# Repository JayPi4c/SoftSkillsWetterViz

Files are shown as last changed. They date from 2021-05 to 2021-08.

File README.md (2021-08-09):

# Wetter-L

## Inhaltsverzeichnis
* [Kurzbeschreibung](#kurzbeschreibung)
* [Inbetriebnahme](#inbetriebnahme)
  * [Demo](#demo)
* [Hardware](#hardware)
* [Software](#software)
  * [Bibliotheken](#bibliotheken)
  * [Boardmanager](#boardmanager)
  * [Code](#code)
* [Features](#features)
  * [Darstellung des Wetters](#darstellung-des-wetters)
  * [Darstellung einer Animation](#darstellung-einer-animation)

## Kurzbeschreibung

Dieser Code gehört zu dem Wetter-Gadget, welches für das Modul Soft Skills und technische Kompetenzen als Semester-Projekt ensteht. Die Aufgabe war es, Wetterdaten, bereitgestellt von [OpenWeatherMap](https://openweathermap.org/), mittels eines WiFi-Fähigen Arduinos und LEDs darzustellen.

Weitere Bedingungen des Projektes waren es, dass mindestens ein Teil des Gadgets aus dem 3D-Drucker kommen oder mit dem Laser-Cutter ausgeschnitten worden sein sollte. Nach einem differenziertem Brainstorming sind wir zu folgenden Prototypen gekommen:
Prototyp

## Inbetriebnahme
Um das Gadget starten zu können muss der Code heruntergeladen werden. Sind die entsprechenden [Biblitheken](#bibliotheken) und der [Boardmanager](#boardmanager) installiert, muss nur noch die `secrets.h` Datei erstellt und mit Inhalt gefüllt werden. Dies lässt sich durch kopieren des Inhalts aus der `secrets_example.h` erreichen, webei die Variablen noch mit den persönlichen Daten gefüllt werden müssen. `SSID` und `Passwort` beziehen sich auf das lokale WLAN-Netzwerk mit dem sich der Mikro-Controller verbinden soll. Den Schlüssel für `OWM_API_KEY` erhält man kostenlos von [OpenWeatherMap.org](https://openweathermap.org/price) nach einer Anmeldung. Den Token für die `BLYNK_API_KEY`-Variable erhält man aus der Blynk App, nachdem man den QR-Code eingescannt hat.
WhatsApp Image 2021-04-09 at 17 00 35

### Demo
Demo-Video (https://www.youtube.com/watch?v=5HPHukewiGE)

## Hardware
- LOLIN(WEMOS) D1 mini Lite 
- LED-Stripe
- LED

## Software

### Bibliotheken
- FastLED (v3.3.3)
- ArduinoJson (v6.17.2)
- Blynk (v1.0.0-beta.3)
### Boardmanager
Um für den ESP8266 Code kompilieren zu können, muss in den Arduino Einstellungen im Menüpunkt "weitere Board manager URLs" folgender Link hinzugefügt werden: http://arduino.esp8266.com/stable/package_esp8266com_index.json. Anschließend kann der entsprechend Board Manager von Arduino heruntergeladen werden.

### Code
Der Code lässt sich grob in vier Abschnitte unterteilen:
* Bibliotheken und globale Variablen
* Einbindung der Blynk API
* `setup`- und `loop`-Funktionen
* weitere Helper-Funktionen

Um zu verstehen, wie die Anbindung mit Blynk funktioniert ist die [Dokumentation](https://docs.blynk.cc/) der beste Ort für Fragen und um ein Verständis zu entwickeln.
In der `setup`-Funktion wird der LED-Streifen initialisiert und eine Verbindung zu Blynk aufgebaut. Hierbei werden vor dem Verbindungsaufbaue alle Scheiben mit einer zufälligen Farbe initialisiert. Konnte eine Verbindung hergestellt werden, so gehen alle LEDs aus und es werden die Wetterdaten von der API bezogen und dargstellt. Sollte ein Fehler auftreten, so leuchten alle Scheiben rot auf.
In der `loop`-Funktion werden, abhängig von dem aktuellen Modus neue Wetterdaten bezogen oder es wird eine Animation dargestellt. Hierbei wird sich viel der Helper-Funktionen bedient.

Diagramm

Die Helper-Funktionen umfassen Methoden zur Darstellung der Wetterdaten und zum anfordern der Wetterdaten, aber auch kleine Funktionen, welche dafür sorgen, dass man ohne großen Aufwand die richtige Scheibe mit einer Farbe beleuchtet kann. Hervorzuheben ist hier allerdings, dass die Funktion `void applyConditions(bool forceUpadte)` schon einmal oben definiert sein muss, da Arduino sonst Probleme damit hat, das Standard-Argument für die Funktion anzunehmen. Ohne Standard-Argument ist die Definition des Funktions-Kopfes nicht notwendig.

## Features
Das Gadget lässt sich auf zwei Grundmodi reduzieren:
* Darstellung der aktuellen Wetterdaten
* Darstellung einer Animation

### Darstellung des Wetters

Für die Darstellung des Wetters wurden die Obergruppen der OpenWeatherMap-API verwendet. Diese umfassen:
* Sonnig
* Bewölkt
* Regnerisch
* Gewitter
* Niesel
* Schnee
* "Atmosphere"

Durch empfangen unterschiedlicher Wetterverhältnisse werden die Scheiben unterschiedlich beleuchtet und man kann das Wetter erkennen.

Im Einstellungs-Tab in der Blynk-App kann zudem noch der Ort eingestellt werden, für den die Daten bezogen werden sollen. Es ist also nicht notwendig, dies vor dem Hochladen festzulegen. Weiterhin lässt sich in dem Tab auch einstellen, in welchen Intervallen der Controller nach Updates suchen soll. Einzustellen ist ein Intervall zwischen 5 und 120 Minuten. 

### Darstellung einer Animation

Neben der Darstellung des Wetters gibt es auch verschieden Animationsmodi, welche das gesamte Gerät in schönen Farben erleuchten lassen. Um zu erkenne, dass sich das Gerät aktuell in einer Animation beindet und nicht die Wetterdaten dargestellt werden, leuchtet dauerhaft die obere LED. Die Animationen umfassen aktuell:
* Darstellung des Wetters (unabhängig des wirklichen Wetters)
* Individuelle Einfärbung der einzelnen Scheiben
* Farb-Fading Animationen

Bei der Darstellung des Wetters kann begutachtet werden, wie ein empfangenes Wetter dargestellt wird. Insbesondere in der Entwicklung ist dies sehr wertvoll, kann auch auch für den Endnutzer von Interesse sein, um zu sehen, wie welches Wetter aussieht.

Die individuelle Einfärbung erlaubt es den Nutzer jeder Scheibe eine inidviduelle Farbe zu geben und so das Gerät in einem einzigartigen glanz erscheinen zu lassen.

Die Farb-Fading Animationen sind Farbverläufe über die Scheiben und geben so ein harmonisch, faszinierendes Erscheinungsbild. Besonders hervorzuheben sind aktuell `Bounce fade` und `Offsetfade` in der App, welche beide besonders gelungene Animationen starten.

Neben diesen verschiedenen Darstellungen gibt es auch die Möglichkeit, das Gadget komplett abzudunkeln, sodass keine Lampe mehr leuchtet. Besonders im Schlafzimmer kann dies von großem Interesse sein. Dies lässt sich sowohl manuell, sowie auch per Zeitsteurung machen.

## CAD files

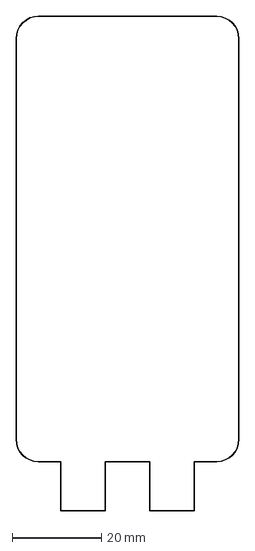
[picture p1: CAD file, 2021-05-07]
Modell/DXF/acryl_blank.dxf
50.0 x 111.0 mm

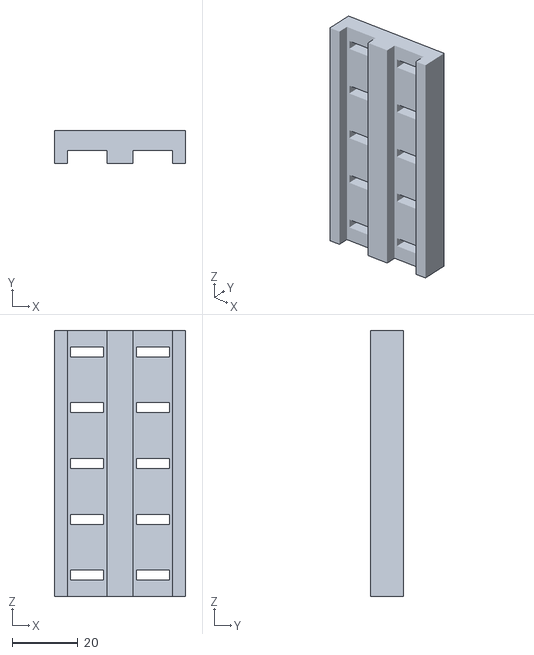
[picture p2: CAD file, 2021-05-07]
Modell/STL/pane_stabilisator.stl
40.0 x 10.0 x 81.0

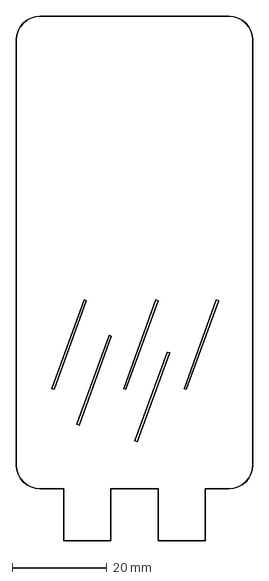
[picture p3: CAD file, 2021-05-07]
Modell/DXF/acryl_rain.dxf
50.0 x 111.0 mm

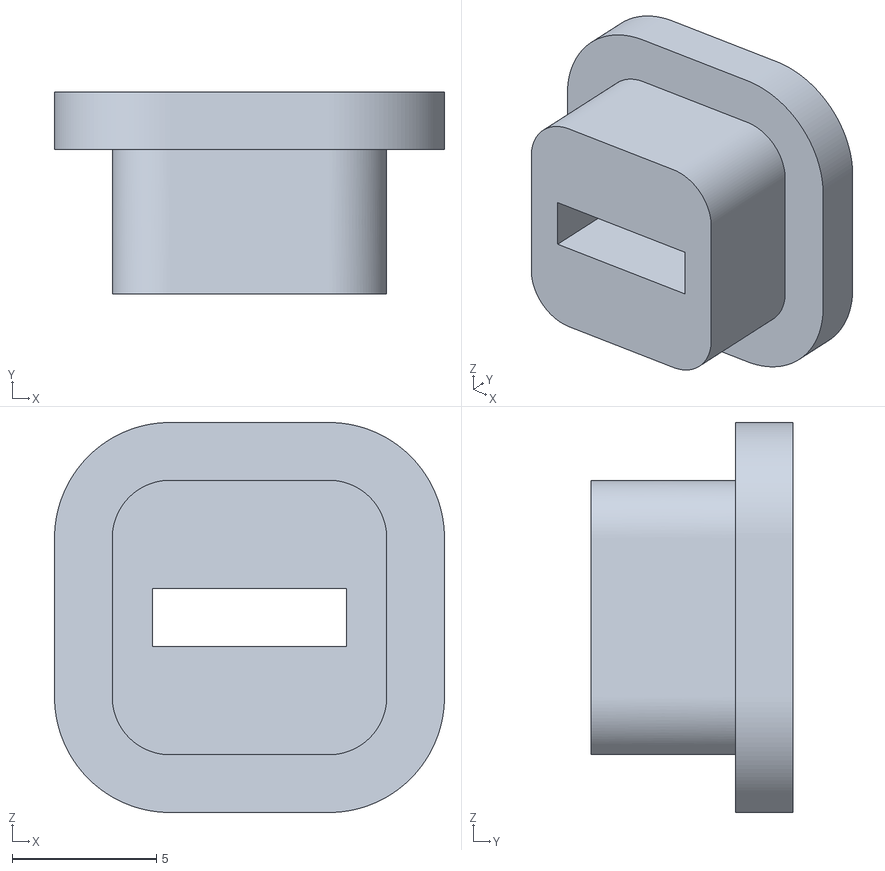
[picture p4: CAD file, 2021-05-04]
Modell/STL/led_stand.stl
13.5 x 7.00 x 13.5

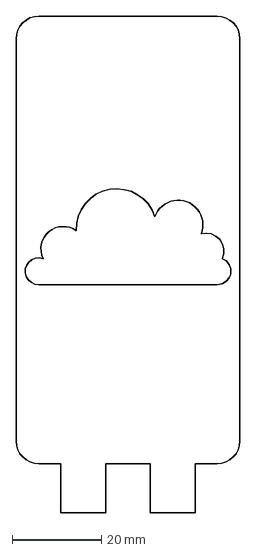
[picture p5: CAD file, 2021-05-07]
Modell/DXF/acryl_cloud.dxf
50.0 x 111.0 mm

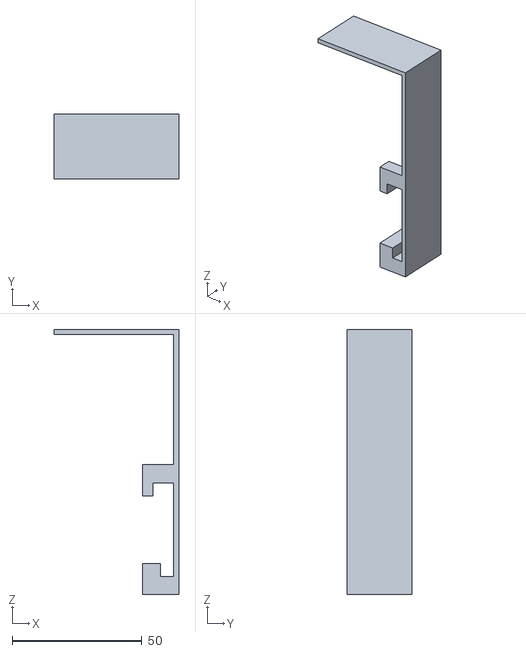
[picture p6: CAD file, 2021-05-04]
Modell/STL/ESP_stand.stl
48.0 x 25.0 x 102.0

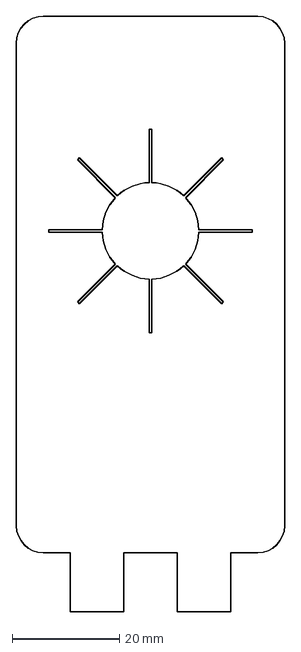
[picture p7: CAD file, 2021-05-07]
Modell/DXF/acryl_sun.dxf
50.0 x 111.0 mm

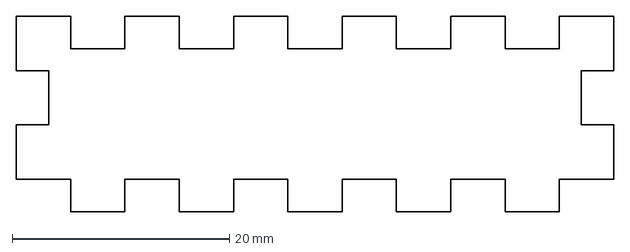
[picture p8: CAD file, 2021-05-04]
Modell/DXF/wood_front.dxf
55.0 x 18.0 mm

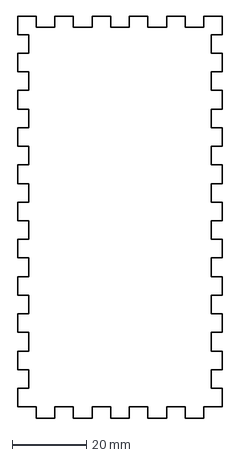
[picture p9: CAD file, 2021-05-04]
Modell/DXF/wood_front_big.dxf
55.0 x 108.0 mm

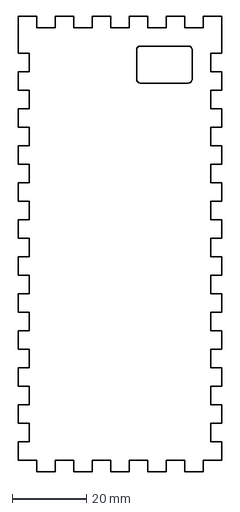
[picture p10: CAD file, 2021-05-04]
Modell/DXF/wood_back.dxf
55.0 x 123.0 mm

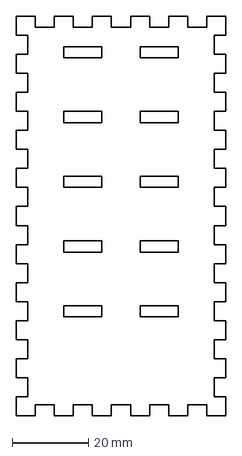
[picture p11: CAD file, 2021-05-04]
Modell/DXF/wood_top_middle.dxf
55.0 x 105.0 mm

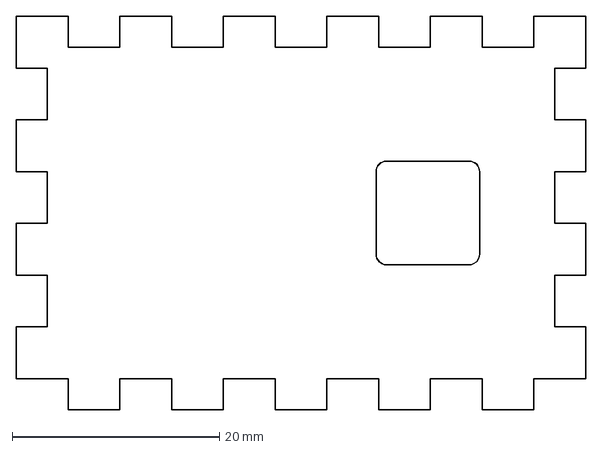
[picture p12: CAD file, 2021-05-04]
Modell/DXF/wood_top.dxf
55.0 x 38.0 mm

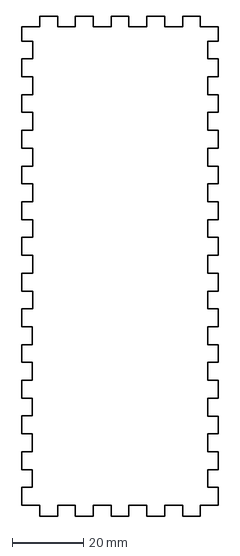
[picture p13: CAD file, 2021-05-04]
Modell/DXF/wood_bottom.dxf
55.0 x 140.0 mm

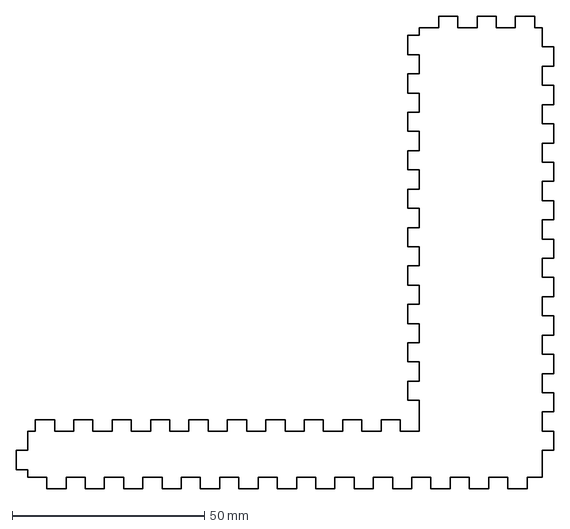
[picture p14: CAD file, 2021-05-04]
Modell/DXF/wood_side.dxf
140.0 x 123.0 mm

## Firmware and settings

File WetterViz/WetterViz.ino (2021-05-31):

// einbinden der geheimen Daten
#include "secrets.h"

// einbinden weiterer Bibliotheken
#include <ArduinoJson.h>
#define FASTLED_INTERNAL  // define to stop FastLED Pragma, comment out to get \
                          // more information
#include <FastLED.h>
//#include "WiFiManager.h"

// BLYNK
#define BLYNK_PRINT Serial
#include <BlynkSimpleEsp8266.h>
#include <WidgetRTC.h>

// Weitere Definitionen
#define DATA_PIN D3
#define NUM_LEDS 10

#define TOP_LED D2

// LED Stripe
CRGB leds[NUM_LEDS];

// WiFi setup
// WiFiManager wifiManager;
WiFiClient client;

bool lightsOn = true;
bool isActive = true;

bool topLightOn = false;

uint8_t brightness = 255;

bool dimBySun = false;
uint8_t dimTime = 15;  // time in which the light is dimmed (minutes)
uint8_t dimMin = 30;
uint8_t dimMax = 255;
unsigned long sunrise;
unsigned long sunset;

WidgetLCD lcd(V16);  // used to show the sunrise and -set time in Blynk APP

uint32_t DIMMING_INTERVAL = 30000;  // every 30 seconds
unsigned long lastcheckDimming = 0;

BlynkTimer timer;
WidgetRTC rtc;

int prev_weatherID = 0;
int weatherID = 0;
int prev_temperature_Celsius = 15;
int temperature_Celsius = 15;

const uint8_t NUM_PANES = 5;

// lookup table um die LEDs für die jeweiligen Platten zu finden.
const uint8_t PANES_LOOKUP[NUM_PANES][2] = {
  { 4, 5 }, { 3, 6 }, { 2, 7 }, { 1, 8 }, { 0, 9 }
};

enum PANES { FRONT,
             RAIN,
             CLOUD,
             SUN,
             BACK };

uint32_t INTERVAL = 900000;
unsigned long lastcheck = 0;

String CITY = "Oldenburg";
String countryCode = "DE";

uint8_t animationMode = 0;
CHSV animColor = CHSV(0, 255, 255);

// define functions to allow default parameter
void applyConditions(bool forceUpdate = false);

void updateBrightness(int b, bool applyOnActive = true);

BLYNK_CONNECTED() {
  rtc.begin();
}

// allows to turn on and off the device via the App
BLYNK_WRITE(V1) {
  setLights(true);
  if (param.asInt()) {
    setActive();
  } else {
    setInactive();
    FastLED.clear();
    FastLED.show();
  }
}

// allow conditions update on user input
BLYNK_WRITE(V2) {
  setLights(true);
  if (param.asInt()) {
    setActive();
    lastcheck = millis();
  }
  Blynk.virtualWrite(V1, HIGH);
}

// light up panes for weather conditions indepent of the real weather
// turns off the update functionality
BLYNK_WRITE(V3) {
  setLights(true);
  setInactive();
  animationMode = 255;

  switch (param.asInt()) {
    case 1:  // clear
      weatherID = 800;
      break;
    case 2:  // cloudy
      weatherID = 801;
      break;
    case 3:  // rainy
      weatherID = 500;
      break;
    case 4:  // snowy
      weatherID = 600;
      break;
    case 5:  // thunderstorm
      weatherID = 200;
      break;
    case 6:  // drizzle
      weatherID = 300;
      break;
    case 7:  // atmosphere
      weatherID = 700;
      break;
    default:  // error
      weatherID = -1;
  }
  applyConditions(true);
}

// sets the pane index which should light up in custom color
int8_t paneIndex = -1;
BLYNK_WRITE(V4) {
  paneIndex = param.asInt() - 1;
  if (paneIndex == 5)
    paneIndex = -1;
}

// function to light up panes with a color received from Blynk
// turns off the update functionality
BLYNK_WRITE(V5) {
  setLights(true);
  setInactive();

  int red = param[0].asInt();
  int green = param[1].asInt();
  int blue = param[2].asInt();

  if (paneIndex == -1) {
    for (uint8_t i = 0; i < NUM_PANES; i++) {
      showPane(i, CRGB(red, green, blue));
    }
  } else {
    showPane(paneIndex, CRGB(red, green, blue));
  }
}

BLYNK_WRITE(V6) {
  setLights(true);
  setInactive();
  animationMode = param.asInt();
}

// allow user to completely disable lights
BLYNK_WRITE(V7) {
  setLights(param.asInt());
}

// Timer to turn off lights between certain times
BLYNK_WRITE(V8) {
  setLights(param.asInt());
}

// setting city to userinput
BLYNK_WRITE(V9) {
  CITY = param.asString();
  setActive();
  lastcheck = millis();
  Blynk.virtualWrite(V1, HIGH);
  // Serial.print("Changing city to ");Serial.println(CITY);
}

// setting country code to userinput
BLYNK_WRITE(V10) {
  countryCode = param.asString();
  // Serial.print("Changing country code to ");Serial.println(countryCode);
}

// setting update interval to user input
BLYNK_WRITE(V11) {
  INTERVAL = param.asInt() * 60000l;
  setActive();
  lastcheck = millis();
  Blynk.virtualWrite(V1, HIGH);
  // Serial.print("Changing Updateinterval to ");Serial.println(INTERVAL);
}

// change brightness of panes
BLYNK_WRITE(V12) {
  dimBySun = false;
  Blynk.virtualWrite(V15, dimBySun);
  updateBrightness(param.asInt());
}

// allow to turn on and off the top LED
BLYNK_WRITE(V13) {
  if (isActive) {  // dont turn on top LED, for real weather
    Blynk.virtualWrite(V13, LOW);
  } else {
    topLightOn = param.asInt();
    if (topLightOn) {
      digitalWrite(TOP_LED, HIGH);
    } else
      digitalWrite(TOP_LED, LOW);
  }
}

// get todays sunrise and -set time.
BLYNK_WRITE(V14) {
  getCurrentWeatherConditions();
}

// allow dimming by sunposition
BLYNK_WRITE(V15) {
  dimBySun = param.asInt();
  if (dimBySun) {
    time_t t = now();
    int bright = brightness;
    if (t < sunrise - dimTime * 60) {
      bright = dimMin;
    } else if (t > sunrise && t < sunset) {
      bright = dimMax;
    } else if (t > sunset + dimTime * 60) {
      bright = dimMin;
    }
    updateBrightness(bright);
  }
}

void setup() {
  Serial.begin(115200);

  // init top LED and turn on.
  pinMode(TOP_LED, OUTPUT);
  digitalWrite(TOP_LED, HIGH);

  // init LED stripe
  FastLED.addLeds<WS2812B, DATA_PIN, GRB>(leds, NUM_LEDS)
    .setCorrection(TypicalLEDStrip);
  FastLED.setMaxPowerInVoltsAndMilliamps(5, 400);
  FastLED.clear();
  FastLED.show();
  // FastLED.setBrightness(255);

  // set all panes to random color
  for (uint8_t i = 0; i < NUM_PANES; i++) {
    showPane(i, CRGB(random(0, 255), random(0, 255), random(0, 255)));
  }

  // init WiFi
  // 192.168.4.1 configuration IP
  // wifiManager.autoConnect("Wetter-Gadget");

  // Serial.println(wifiManager.getWiFiPass());
  // Serial.println(wifiManager.getWiFiSSID());

  // connect to Blynk
  Blynk.begin(BLYNK_API_KEY, ssid, pass, BLYNK_SERVER, BLYNK_PORT);
  setSyncInterval(10 * 60);

  // turn off panes when connected
  FastLED.clear();
  FastLED.show();

  // get initial weather conditions and apply them to the panes
  // getCurrentWeatherConditions();
  // applyConditions();

  // turn off LED on top, when connected and inform Blynk-App that the panes are
  // active
  // digitalWrite(TOP_LED, LOW);
  // Blynk.virtualWrite(V12, HIGH);

  // write the default settings to Blynk App
  Blynk.virtualWrite(V9, CITY);
  Blynk.virtualWrite(V10, countryCode);
  Blynk.virtualWrite(V11, INTERVAL / 60000l);
  Blynk.virtualWrite(V12, brightness);
  Blynk.virtualWrite(V13, topLightOn);
  Blynk.virtualWrite(V15, dimBySun);

  setActive();
}

void loop() {
  Blynk.run();
  timer.run();

  // if lights are off don't apply conditions or do an animation
  if (!lightsOn)
    return;

  if (dimBySun) {
    time_t t = now();
    int bright = brightness;
    if (t > sunrise - dimTime * 60 && t < sunrise) {
      bright = map(t, sunrise - dimTime * 60, sunrise, dimMin, dimMax);
    } else if (t > sunset && t < sunset + dimTime * 60) {
      bright = map(t, sunset, sunset + dimTime * 60, dimMax, dimMin);
    }
    if (bright != brightness) {
      if (!isActive) {
        updateBrightness(bright);
      } else {
        if (millis() - lastcheckDimming >= DIMMING_INTERVAL) {
          updateBrightness(bright);
          lastcheckDimming = millis();
        } else {
          updateBrightness(bright, false);
        }
      }
    }
  }

  if (isActive) {
    // get regularly new weather data
    if (millis() - lastcheck >= INTERVAL) {
      getCurrentWeatherConditions();
      lastcheck = millis();
      applyConditions();
    } else if ((weatherID / 100) == 2) {
      // thunderstorm has extra animation
      if (random(1000) < 8) {
        showPane(CLOUD, CRGB(255, 255, 255));
        showPane(RAIN, CRGB(255, 255, 0));
      } else {
        showPane(CLOUD, CRGB(60, 60, 60));
        showPane(RAIN, CRGB(0, 0, 255));
      }
    }

  } else {
    doAnimation();
  }
}

uint8_t animCounter = 0;
int8_t animInc = 1;
void doAnimation() {
  CRGB rgb;
  uint8_t offset = 255 / NUM_PANES;
  switch (animationMode) {
    case 0:
      // do nothing;
      break;
    case 1:
      FastLED.clear();
      break;
    case 2:
      // it iterates really fast over all the colors. Maybe a small timeout would
      // be apropiate.

      hsv2rgb_rainbow(animColor, rgb);
      for (uint8_t i = 0; i < NUM_PANES; i++) {
        showPane(i, rgb);
      }
      animColor.h++;
      animColor.h = animColor.h % 255;
      break;
    case 3:
      hsv2rgb_rainbow(animColor, rgb);
      for (uint8_t i = 0; i < NUM_PANES; i++) {
        hsv2rgb_rainbow(
          CHSV(animColor.h + (i * offset), animColor.s, animColor.v), rgb);
        showPane(i, rgb);
      }
      animColor.h++;
      animColor.h = animColor.h % 255;
      break;
    case 4:
      // this mode is still experimental.
      hsv2rgb_rainbow(animColor, rgb);
      showPane(animCounter, rgb);
      for (uint8_t i = 0; i < NUM_PANES; i++) {
        if (i == animCounter)
          continue;
        showPane(i, CRGB(255, 255, 255));
      }
      animColor.h++;
      if (animColor.h >= 255) {
        animColor.h = 0;
        ++animCounter %= NUM_PANES;
      }
      delay(10);
      break;
    case 5:
      hsv2rgb_rainbow(animColor, rgb);
      for (uint8_t i = 0; i < NUM_PANES; i++) {
        hsv2rgb_rainbow(
          CHSV(animColor.h + (i * offset), animColor.s, animColor.v), rgb);
        showPane(i, rgb);
      }
      animColor.h += animInc;
      animColor.h = animColor.h % 255;
      animCounter++;
      if (animCounter == 0) {
        animInc *= -1;
        animColor.h = 255;
      }
      break;
    case 255:
      if ((weatherID / 100) == 2) {
        if (random(1000) < 8) {
          showPane(CLOUD, CRGB(255, 255, 255));
          showPane(RAIN, CRGB(255, 255, 0));
        } else {
          showPane(CLOUD, CRGB(60, 60, 60));
          showPane(RAIN, CRGB(0, 0, 255));
        }
      }
      break;
  }
  FastLED.show();
}

// The IDs definitions can be found online:
// https://openweathermap.org/weather-conditions
void applyConditions(bool forceUpdate) {

  // we only need to make changes to the leds if the conditions have changed
  if (!forceUpdate && prev_weatherID == weatherID && prev_temperature_Celsius == temperature_Celsius) {
    // Serial.println("id has not changed... skipping!");
    // Serial.print(prev_weatherID); Serial.print("==");
    // Serial.println(weatherID);
    return;
  }

  FastLED.clear();

  // turn off the front pane
  showPane(FRONT, CRGB(0, 0, 0));

  // color the front pane according to the current temperature
  if (temperature_Celsius < 10) {
    showPane(BACK, CRGB(0, 0, 255));
  } else if (temperature_Celsius > 20) {
    showPane(BACK, CRGB(255, 0, 0));
  } else {
    showPane(BACK, CRGB(255, 94, 29));
  }

  if (weatherID == 800) {  // clear sky
    showPane(SUN, CRGB(255, 190, 90));
    FastLED.show();
    // Serial.println("Clear sky");
    return;
  }

  int8_t id = weatherID / 100;  // reduce the id to the main definition
  // Serial.println();
  // Serial.print("weatherID is "); Serial.println(weatherID);
  // Serial.print("ID is "); Serial.println(id);

  switch (id) {
    case 2:  // thunderstorm
      // Serial.println("thunderstorm");
      showPane(CLOUD, CRGB(60, 60, 60));
      showPane(RAIN, CRGB(0, 0, 255));
      break;
    case 3:  // drizzle
      // Serial.println("drizzle");
      showPane(CLOUD, CRGB(180, 180, 180));
      showPane(RAIN, CRGB(0, 0, 200));
      break;
    case 5:  // rain
      // Serial.println("rain");
      showPane(CLOUD, CRGB(255, 255, 255));
      showPane(RAIN, CRGB(0, 0, 255));
      break;
    case 6:  // snow
      // Serial.println("snow");
      showPane(CLOUD, CRGB(255, 255, 255));
      showPane(RAIN, CRGB(255, 255, 255));
      break;
    case 7:  // atmosphere
      // Serial.println("atmosphere");
      showPane(CLOUD, CRGB(180, 180, 180));
      showPane(RAIN, CRGB(180, 180, 180));
      break;
    case 8:  // clouds
      // Serial.println("clouds");
      showPane(SUN, CRGB(255, 190, 90));
      showPane(CLOUD, CRGB(180, 180, 180));
      break;
    default:
      // Serial.println("error");
      CRGB col = CRGB(255, 0, 0);
      for (uint8_t i = 0; i < NUM_PANES; i++) {
        showPane(i, col);
      }
  }
  FastLED.show();
  // Serial.println("All done!");
}

void getCurrentWeatherConditions() {
  Serial.println("connecting to api.openweathermap.org");
  // get data from api
  if (client.connect("api.openweathermap.org", 80)) {
    client.println("GET /data/2.5/weather?q=" + CITY + "," + countryCode + "&units=metric&lang=de&APPID=" + OWM_API_KEY);
    client.println("Host: api.openweathermap.org");
    client.println("Connection: close");
    client.println();
  } else {
    Serial.println("connection failed");
  }
  const size_t capacity = JSON_ARRAY_SIZE(2) + 2 * JSON_OBJECT_SIZE(1) + 2 * JSON_OBJECT_SIZE(2) + 2 * JSON_OBJECT_SIZE(4) + JSON_OBJECT_SIZE(5) + JSON_OBJECT_SIZE(6) + JSON_OBJECT_SIZE(14) + 360;
  DynamicJsonDocument doc(capacity);
  // create json from api's data
  deserializeJson(doc, client);
  client.stop();

  // set variables according to api answer
  prev_weatherID = weatherID;
  weatherID = doc["weather"][0]["id"];
  prev_temperature_Celsius = temperature_Celsius;
  temperature_Celsius = doc["main"]["temp"];
  long tz = doc["timezone"];
  sunrise = doc["sys"]["sunrise"];
  sunrise += tz;
  sunset = doc["sys"]["sunset"];
  sunset += tz;

  printSunposition();
  // serializeJson(doc, Serial);Serial.println();
}

void showPane(uint8_t pane, CRGB color) {
  for (uint8_t i = 0; i < 2; i++) {
    leds[PANES_LOOKUP[pane][i]] = color;
  }
  FastLED.show();
}

void setLights(bool on) {
  lightsOn = on;

  if (!lightsOn) {
    Blynk.virtualWrite(V7, LOW);
    Blynk.virtualWrite(V13, LOW);
    FastLED.clear();
    FastLED.show();
    digitalWrite(TOP_LED, LOW);
  } else {
    Blynk.virtualWrite(V7, HIGH);
    if (isActive) {
      applyConditions(true);
    } else if (topLightOn)
      digitalWrite(TOP_LED, HIGH);
    Blynk.virtualWrite(V13, topLightOn);
    if (dimBySun) {
      time_t t = now();
      int bright = brightness;
      if (t < sunrise - dimTime * 60) {
        bright = dimMin;
      } else if (t > sunrise && t < sunset) {
        bright = dimMax;
      } else if (t > sunset + dimTime * 60) {
        bright = dimMin;
      }
      updateBrightness(bright);
    }
  }
}

void setActive() {
  isActive = true;
  topLightOn = false;
  Blynk.virtualWrite(V13, topLightOn);
  getCurrentWeatherConditions();
  applyConditions(true);
  digitalWrite(TOP_LED, LOW);
  Blynk.virtualWrite(V1, HIGH);
  Blynk.virtualWrite(V7, HIGH);
}

void setInactive() {
  isActive = false;
  animationMode = 0;
  topLightOn = true;
  Blynk.virtualWrite(V13, HIGH);
  digitalWrite(TOP_LED, HIGH);
  Blynk.virtualWrite(V1, LOW);
}

void updateBrightness(int b, bool applyOnActive) {
  brightness = b;
  FastLED.setBrightness(brightness);
  if (isActive && applyOnActive) {
    applyConditions(true);
  }
  Blynk.virtualWrite(V12, brightness);
}


// This function is used to show when sunrise and -set are timed and when the automated dimming should apply.
void printSunposition() {
  lcd.print(0, 0, "Sun↑: ");

  int val = hour(sunrise);
  if (val < 10) {
    lcd.print(6, 0, "0");
    lcd.print(7, 0, val);
  } else
    lcd.print(7, 0, val);

  lcd.print(8, 0, ":");

  val = minute(sunrise);
  if (val < 10) {
    lcd.print(9, 0, "0");
    lcd.print(10, 0, val);
  } else
    lcd.print(9, 0, val);

  lcd.print(0, 1, "Sun↓: ");

  val = hour(sunset);
  if (val < 10) {
    lcd.print(6, 1, "0");
    lcd.print(7, 1, val);
  } else
    lcd.print(6, 1, val);

  lcd.print(8, 1, ":");

  val = minute(sunset);
  if (val < 10) {
    lcd.print(9, 1, "0");
    lcd.print(10, 1, val);
  } else
    lcd.print(9, 1, val);
}

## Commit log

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2021-03-22 Adding WiFi connectivity
    Der WiFiManager wird nun benutzt und es werden regelmäßig API Abfragen
    an OpenWeatherMap geschickt.
2021-04-01 Adding OpenWeatherMap API functionality
    Die Antwort des API Aufrufes wird nun verarbeitet und die Scheiben
    werden entsprechend des Ergebnisses der API unterschiedlich beleuchtet.
2021-04-01 Adding basic Blynk functionality
    Die Bibliothek wurde eingebunden und es wurde die Möglichkeit
    hinzugefügt per Blynk alle Scheiben in eine Farbe inzufärben.
2021-04-02 Adding top LED
    Die obere LED ist nun auch im Code und kann ensprechend gewünschter
    Funktionalität genutzt werden.
2021-04-02 Adding full Blynk functionality
    Das Gadget kann nun via Blynk an und aus geschaltet werden und
    zusätzlich können die Scheiben auch mit der App die Farbe ändern.
    Da die verwendete Blynk Library ohnehin SSID und Passwort braucht wurde
    der WiFi Manager vorläufig entfernt, da er keinen Merhwert bietet,
    allerdings gibt es auch eine Blynk WiFi Manager Library, die
    möglicherweise eine gute Alternative ist, für die aktuelle Lösung.
2021-04-03 Adding additional Blynk features
    Es können nun alle Scheiben einzeln eingefärbt werden. Außerdem können
    auch die einzelnen Wetterbedingungen dargestellt werden, auch wenn diese
    nicht aktuell vorherschen. Außerdem wurde die Möglichkeit hinzugefügt
    jederzeit die Wetterbedingungen neu zu laden, was auch den Interval zum
    nächsten Update neustartet.
2021-04-04 Adding the animation modes
    Man kann nun per App zwischen (aktuell noch) zwei Animationsmodi
    unterscheiden. Diese sind unabhängig des aktuellen Wetters und zeigen
    nur die Vielfalt der Möglichkeiten.
2021-04-05 Adding two more Animation modes
    Es wurde eine Animation hinzugefügt, welche dafür sorgt, dass alle
    Platten die Farben wechseln, aber alle immer Unterschiedliche Farben
    haben. Außerdem wurde eine Animation hinzugefügt, welche dafür sorgt,
    dass immer ein Platte komplett alle Farben durchgeht und dann erst die
    nächste damit anfängt. Ist eine Platte in diesem Modus nicht am Farben
    wechseln, wird sie weiß beleuchtet. (Diese zweite Animation ist
    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
2021-04-06 Adding possibility to turn off all lights
    Alle Lichter können nun per App deaktiviert werden, sodass keine LED
    mehr leuchtet. Dies erlaubt es, ohne das Gadget komplett vom Strom zu
    trennen, es vollkommen zu verdunkeln.
2021-04-06 Adding Timer functionality
    Es wurde eine Zeitschaltuhr hinzugefügt, welche dafür sorgt, dass man
    einstellen kann, zwischen welchen Zeiten das Gadget an und wann aus ist.
2021-04-06 Adding lighning animation
    Um ein Gewitter besser von Regen untescheiden zu können, wurde eine
    Animation für das Gewitter erstellt. Zu 0.8% wird jeden Durchlauf von
    Loop kein Regen, sondern ein Blitz dargestellt. Dies wird durch
    zufälliges helles aufleuchten der Platten dargestellt.
2021-04-06 Changing to Arduino IDE 2 autoformat scheme
    Da die neue IDE von Arduino ein etwas anderes Autoformat Schema hat, als
    die alte IDE wird hiermit das neue Schema übernommen.
2021-04-06 Change from boolean to bool + dec update interval
    Boolean Variablen wurden zu bool Variablen gemacht, um näher an CPP zu
    sien. Weiterhin wurde der Update Interval verkleinert, um aktuellere
    Daten darzustellen.
2021-04-08 Adding bounce fade
    Es wurde eine neue Animation hinzugefügt, bei der es so aussieht, als
    würde die Fade Animation vorwärts und rückwärts gehen, so als würde die
    Farbe wie eine Welle vor und zurück schwappen.
2021-04-08 Customize settings with App
    Es können nun der Update-Intervall und die Stadt, für welche das Wetter
    angezeigt werden, per App eingestellt werden. Wichtig ist, dass man in
    ter App nach Eingabe der Stadt auch die Eingabe-Taste tippt, da sonst
    die Daten nicht an das Gadget geschickt werden und entsprechend keine
    Updates vorgenommen werden. Besonders wichtig ist das beim Senden des
    Länderkürzels, da es keine Möglichkeit gibt, zu sehen, ob die Daten das
    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
2021-05-04 Adding 3D Model files
    Upload der 3D-Model Dateien in der ersten Verion.
    [Wetterstation.0018.iam, Wetterstation.iam, acryl_blank.dxf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]
2021-05-04 3D Models Version 2
    Es wurden kleine Anpassungen am Modell vorgenommen, um ein besseres
    Design zu erhalten.
    [ESP_stand.ipt, ESP_stand.stl, Wetterstation.0021.iam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]
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2021-05-04 Uploading final 3D-Files
    [ESP_stand.ipt, Wetterstation.0018.iam, Wetterstation.0021.iam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]
2021-05-05 Remove duplicate file
    Die Datei wood_front_small.dxf war identisch zu der Datei
    wood_front.dxf. Aus diesem Grund wurde sie als überflüssig entfernt.
    [wood_front_small.dxf]
2021-05-07 Updating model files
    [ESP_stand.stl, acryl_blank.dxf, acryl_cloud.dxf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]
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2021-05-16 Changing action to work again
    Aus irgendeinem Grund hat die GitHub Action zum kompilieren des Arduino
    Codes nicht mehr funktioniert. Durch entfernen der Exception option in
    der fqbn konnte dies behoben werden.
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
